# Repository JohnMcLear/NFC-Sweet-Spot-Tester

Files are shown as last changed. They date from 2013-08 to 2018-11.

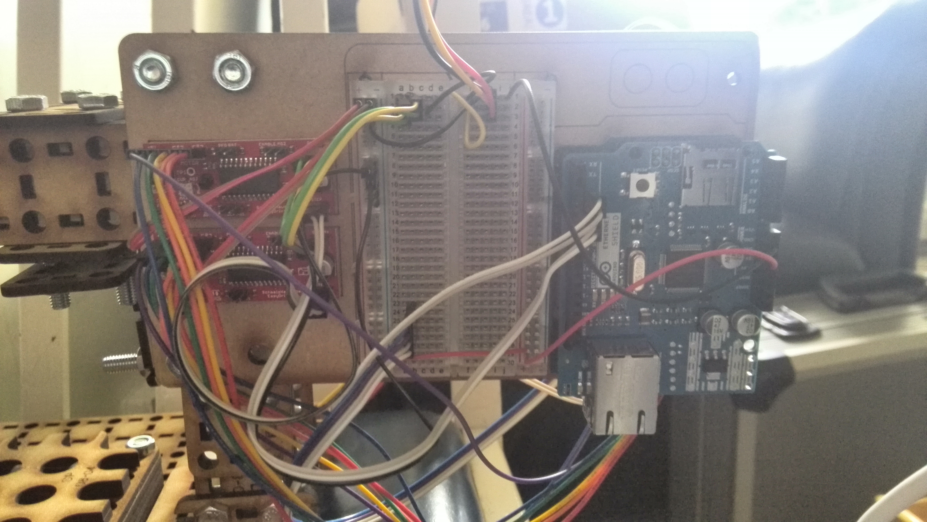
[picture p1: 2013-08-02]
pictures/IMG_20130802_145246.jpg

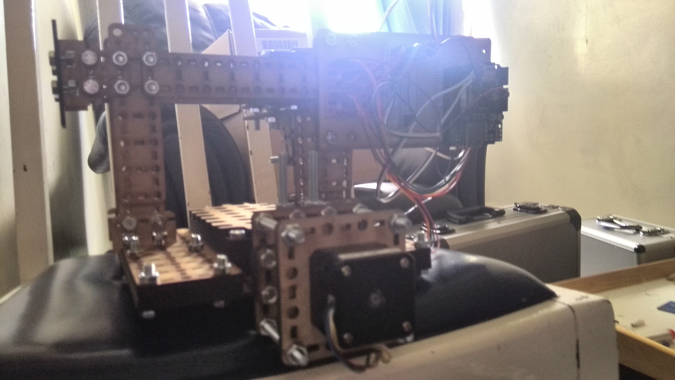
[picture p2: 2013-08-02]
pictures/IMG_20130802_145251.jpg

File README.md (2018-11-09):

# NFC Readability tester

## Description
This hardware/software moves an NFC inlay (or an NFC Ring) over a mobile phone and locates where the NFC Antenna sweet spot is.  The co-ordinates are then stored in a database (in the format x,y,successOrFail[bool]) and can be used to identify how well a specific target device (such as a cell phone or tablet) will function with an NFC Ring.

## What problems does this solve?
Q. Does my [Insert one of a 3000 NFC handsets here] work with the NFC Ring?

A. We will be able to visually show which point each ring will work with the NFC Ring on the specific device.

Q. Where is the sweet spot on my phone?

A. See previous Answer.

Q. Where do I hold the NFC Ring to on my phone.

A. See previous, previous Answer.

## Requirements
* Laser cutter
* Arduino 
* 50x m6 nuts and bolts (Various thread sizes) (see pictures)
* Various cables (see pictures)
* Breadboard
* 2x stepper motors - 4218S-04
* 2x stepper motor controllers - http://www.schmalzhaus.com/EasyDriver/ v4.3+
* Threaded rod
* ATX PSU
* 2x Switch
* Arduino Ethernet Shield
* Some sort of on-slip material IE http://www.amazon.com/Grip-Shelf-Drawer-Liner-Black/dp/B000KFSOFI

## Instructions
* Laser cut the hardware using the files in "laser-cutting"
* Connect all the arduino stuff up and the motors. (See pictures for reference)
* Load up the source, change some variables (See top of source).
* Install NFC Ring App on device, select Scan QR Code.  Scan a QR Code that has http://nfcring.com/NFC-Sweet-Spot-Test encoded (You can encode this at http://nfcring.com/app).  Follow the on screen instructions.
* Power up the Hardware

## License
Apache 2

## Can I purchase one of these bad mofos pre-built?
Negative :(

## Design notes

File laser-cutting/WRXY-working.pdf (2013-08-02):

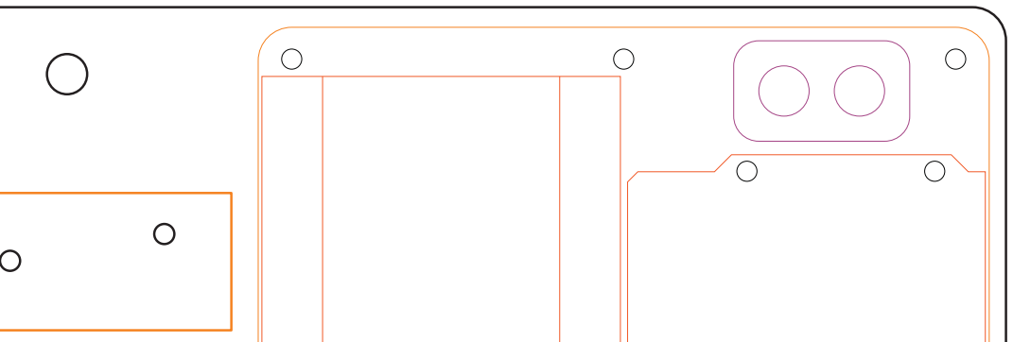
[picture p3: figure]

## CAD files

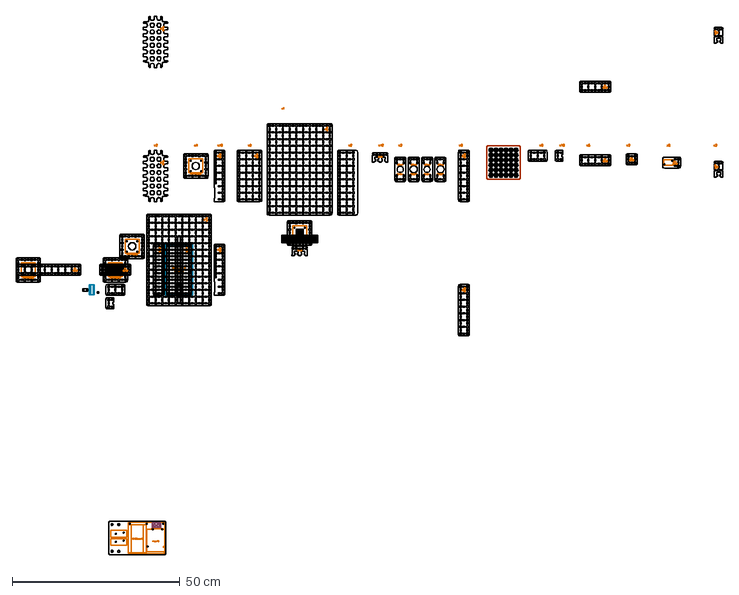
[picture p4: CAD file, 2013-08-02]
laser-cutting/WRXY-working.dxf
211.0 x 160.7 cm

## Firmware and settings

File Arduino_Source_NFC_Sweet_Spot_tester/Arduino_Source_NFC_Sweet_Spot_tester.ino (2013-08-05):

#include <Ethernet.h>
#include <SPI.h>

/*******************************
*
* Ethernet Config
*
********************************/
byte mac[] = { 0xDE, 0xAD, 0xBE, 0xEF, 0xFE, 0xED };
IPAddress ip(192,168,1, 177);
EthernetServer server(80);

/*******************************
*
* PIN DECLARATIONS
*
********************************/

// motors (x and y)
int pinXStep = 2;
int pinXDir = 3;
int pinYStep = 4;
int pinYDir = 5;

// Switches that are triggered when max and min Y are reached
int pinXSwitch = 9;
int pinYSwitch = 8;

/*******************************
*
* ENVIRONMENT DECLARATIONS
*
********************************/

// Variable we use to share X and Y
int x = 0; // current X position
int y = 0; // current Y position

//Direction Variables
int xCCW = LOW;
int xCW = HIGH;
int yCCW = LOW;
int yCW = HIGH;

int step = 10000; // The size of the step to take when resetting

int stepSpeed = 50*5; //milliseconds delay between pulses

long widthSteps = 105000; // The Width we should move across (Y)
long heightSteps = 120000; // The Height we should move across (X)
long widthDivisions = 10; // How many steps across should we take on our journey?
long heightDivisions = 10; // How many steps up should we take on our journey?

int testDelay = 1000; // The delay to wait for to move to the next point
int sampleDelay = 1000; // The delay to wait for the NFC to register.

int reset = 0; // has reset been completed?
int xReset = 0; // is X reset?
int yReset = 0; // is Y reset?

void setup() {
  Serial.begin(9600);
  Serial.println("Setup");
  
  // Begin Ethernet Stuff
  Ethernet.begin(mac, ip);
  server.begin();
  Serial.print("server is at ");
  Serial.println(Ethernet.localIP());
  
  
  // set pin Modes
  //pinMode(pinXSwitch, INPUT);
  //pinMode(pinYSwitch, INPUT);
  
  // delay(500);
  pinMode(pinXStep, OUTPUT);
  pinMode(pinXDir, OUTPUT);

  pinMode(pinYStep, OUTPUT);
  pinMode(pinYDir, OUTPUT);
  
  // delay(500);

}

void loop() {
  
  /*******************************
  *
  * RESET THE MACHINE BACK TO 0,0 
  *
  ********************************/
  
  if (reset == 0){ // Is reset completed yet?  (on first run this is 0)
    // Until PinX Goes High Reset the motor
    Serial.println("Resetting");
    
    if(xReset == 0){
      Serial.println("Resetting X");
      while(digitalRead(pinXSwitch) == 0){ // While the switch isn't depressed
        // Serial.println("Moving X back to 0");
        moveX(-500);
      }
      if(digitalRead(pinXSwitch) == 1){
        xReset = 1; 
      }
    }

    if(yReset == 0){
      Serial.println("Resetting Y");
      Serial.println(digitalRead(pinYSwitch));
      // Until PinY Goes High Reset the motor
      while(digitalRead(pinYSwitch) == 0){ // While the switch isn't depressed
        moveY(-500);
      }
      if(digitalRead(pinYSwitch) == 1){
        yReset = 1; 
      }
    }
    reset = 1; // reset is now completed, yay :)
    x = 0; // current X position is reset
    y = 0; // current Y position
  }

  /*******************************
  *
  * GO OVER THE TARGET DEVICE
  *
  ********************************/
  
  for(int height = 0; height < heightDivisions; height++){
    y = 0; // reset y back to 0
    for(int width = 0; width <  widthDivisions; width++){
      moveY(widthSteps/widthDivisions);
      takeSample();      
    }

    while(digitalRead(pinYSwitch) == 0){ // While the switch isn't depressed
      // Serial.println("Moving Y back to 0");
      moveY(-500);
    }
    delay(testDelay);  
    moveX(heightSteps/heightDivisions);
    delay(testDelay);
  }    
  
  for(int width = 0; width <  widthDivisions; width++){
    moveY(widthSteps/widthDivisions);
    takeSample();      
  }
  
  moveY(-widthSteps);
  moveX(-heightSteps);
  delay(10000);
}
  
  

void takeSample(){
  EthernetClient client = server.available();
  if (client) { // Note that the client will only respond if we're not in a delay (blocking...)
    boolean currentLineIsBlank = true;
    while (client.connected()) {
      if (client.available()) {
        char c = client.read();
        Serial.write(c);
        // if you've gotten to the end of the line (received a newline
        // character) and the line is blank, the http request has ended,
        // so you can send a reply
        if (c == '\n' && currentLineIsBlank) {
          // send a standard http response header
          client.println("HTTP/1.1 200 OK");
          client.println("Content-Type: application/json");
          client.println("Connection: close");  // the connection will be closed after completion of the response
          client.println();
          client.print("{'x':");       
          client.print(x);       
          client.print(",");
          client.print("'y':");       
          client.print(y);      
          client.println("}");
          break;
        }
        if (c == '\n') {
          // you're starting a new line
          currentLineIsBlank = true;
        } 
        else if (c != '\r') {
          // you've gotten a character on the current line
          currentLineIsBlank = false;
        }
      }
    }
    client.stop();
  }
  // End Ethernet stuff
  
  delay(sampleDelay);
}

void moveY(long steps){
   if(steps < 0){ // are we going backwards?
      digitalWrite(pinYDir, yCW);
   }else{
      digitalWrite(pinYDir, yCCW);  
      y = y + (step);
   } 
  for(int i = 0; i < abs(steps); i++){
   digitalWrite(pinYStep, HIGH);
   delayMicroseconds(stepSpeed/2);
   digitalWrite(pinYStep, LOW);
   delayMicroseconds(stepSpeed/2);
  }   
} 
  
void moveX(long steps){
   if(steps < 0){ // are we going backwards?
      digitalWrite(pinXDir, xCW);
   }
   else{
      x = x + (step);
      digitalWrite(pinXDir, xCCW);  
   } 
  for(int i = 0; i < abs(steps); i++){
   digitalWrite(pinXStep, HIGH);
   delayMicroseconds(stepSpeed/2);
   digitalWrite(pinXStep, LOW);
   delayMicroseconds(stepSpeed/2);
  }   
} 

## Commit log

2013-08-02 clena up
    [WRXY-working.dxf]
2013-08-03 arduino source in arduino file
2013-08-04 Working movement and reset
    [Arduino_Source_NFC_Sweet_Spot_tester.ino]
